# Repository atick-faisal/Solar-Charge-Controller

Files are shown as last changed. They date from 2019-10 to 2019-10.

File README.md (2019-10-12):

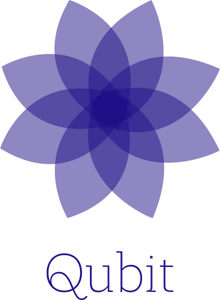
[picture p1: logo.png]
# `Solar-Charge-Controller` 
  

<p align="center">
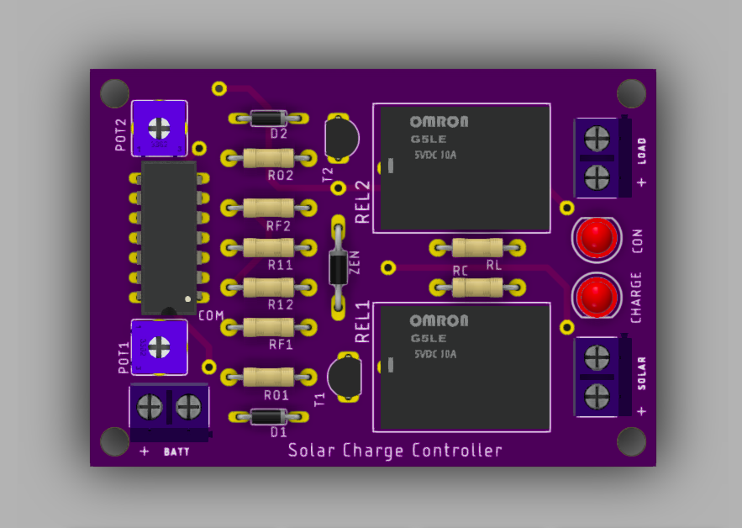
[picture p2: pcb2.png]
  
</p>
<p align="center">
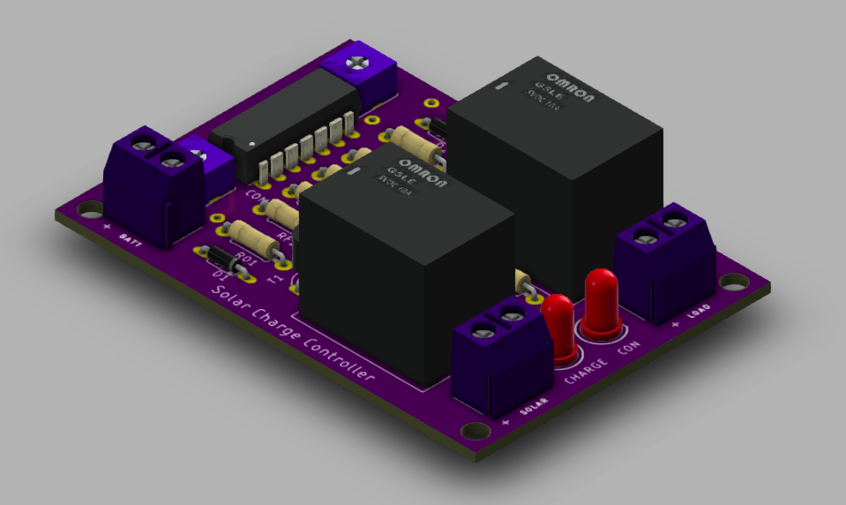
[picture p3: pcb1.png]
  
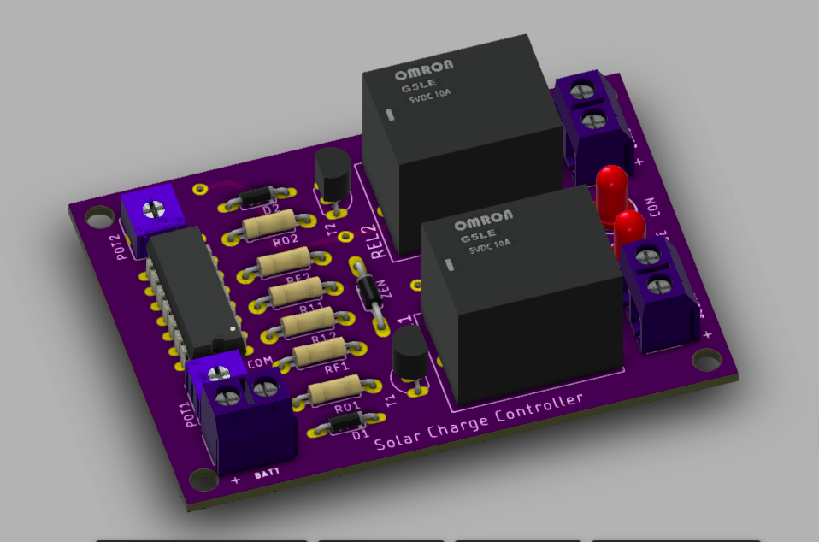
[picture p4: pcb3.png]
  
</p>

## Specifications

 ##### Battery Voltage : 12V
 ##### VR = 14.4V, ARV = 13.0V
 ##### LVD = 10.8V, LRV = 12.5V

## Schematic
<p align="center">
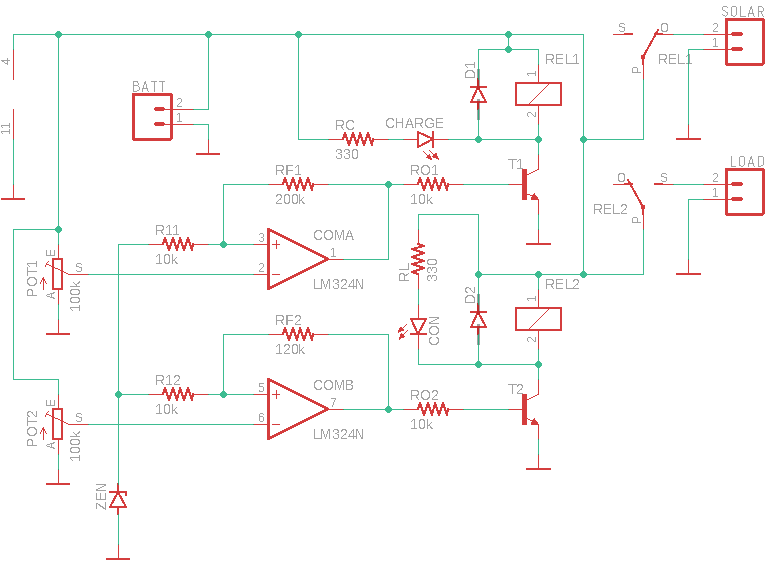
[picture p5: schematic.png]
  
</p>

## Tuning the Circuit
<p align="center">
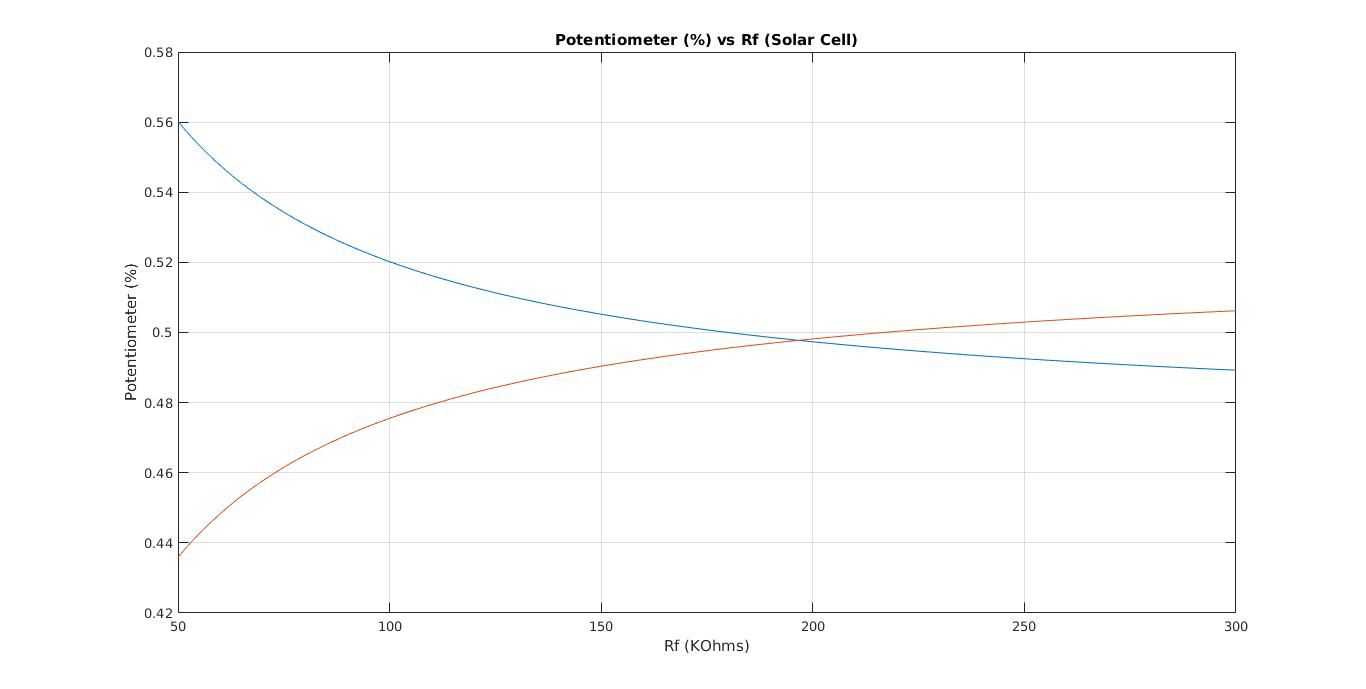
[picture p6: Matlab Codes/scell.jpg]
  
  <br>
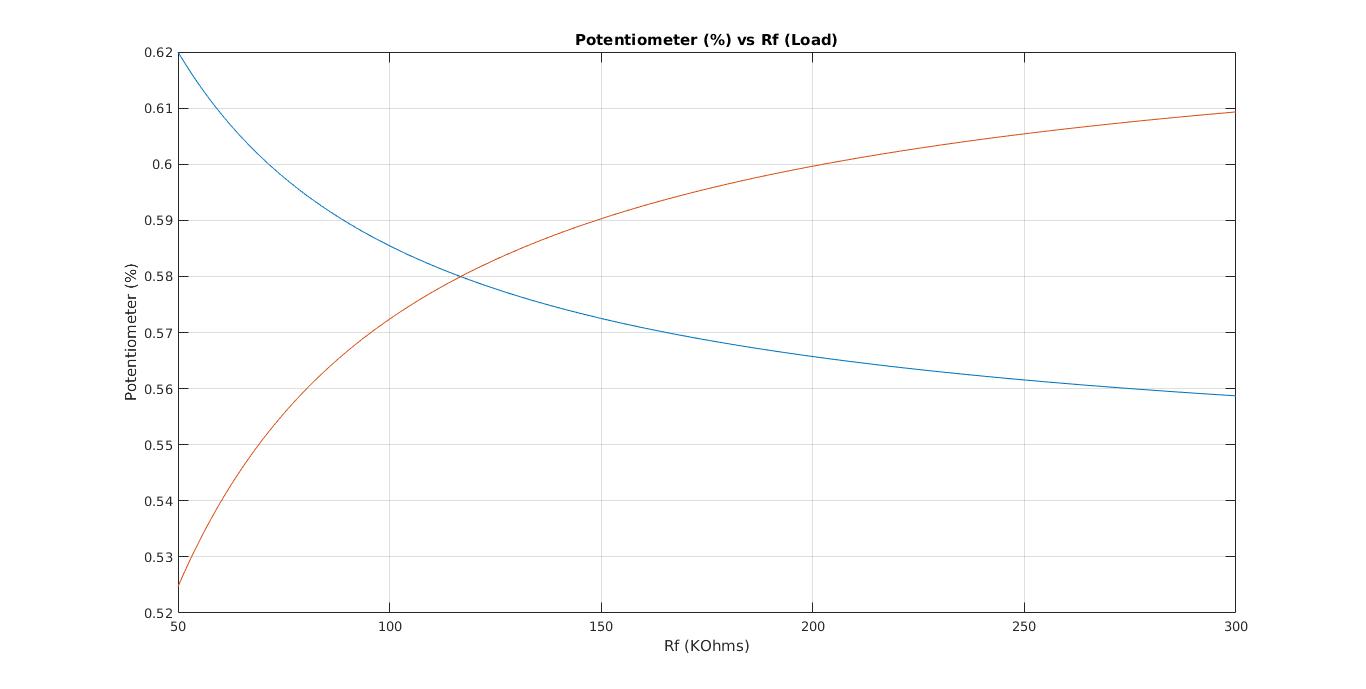
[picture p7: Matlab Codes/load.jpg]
  
</p>

## Simulation Result
<p align="center">
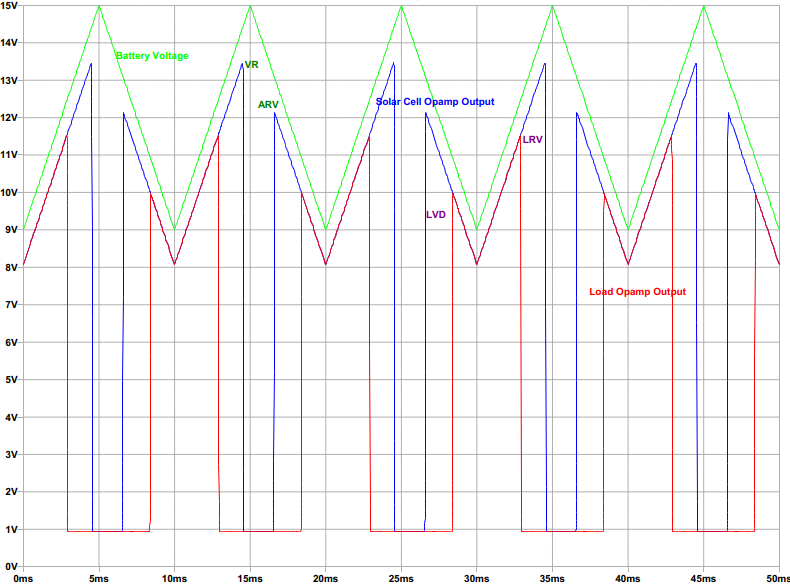
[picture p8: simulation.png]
  
</p>

## License


This work is licensed under `Apache License 2.0`

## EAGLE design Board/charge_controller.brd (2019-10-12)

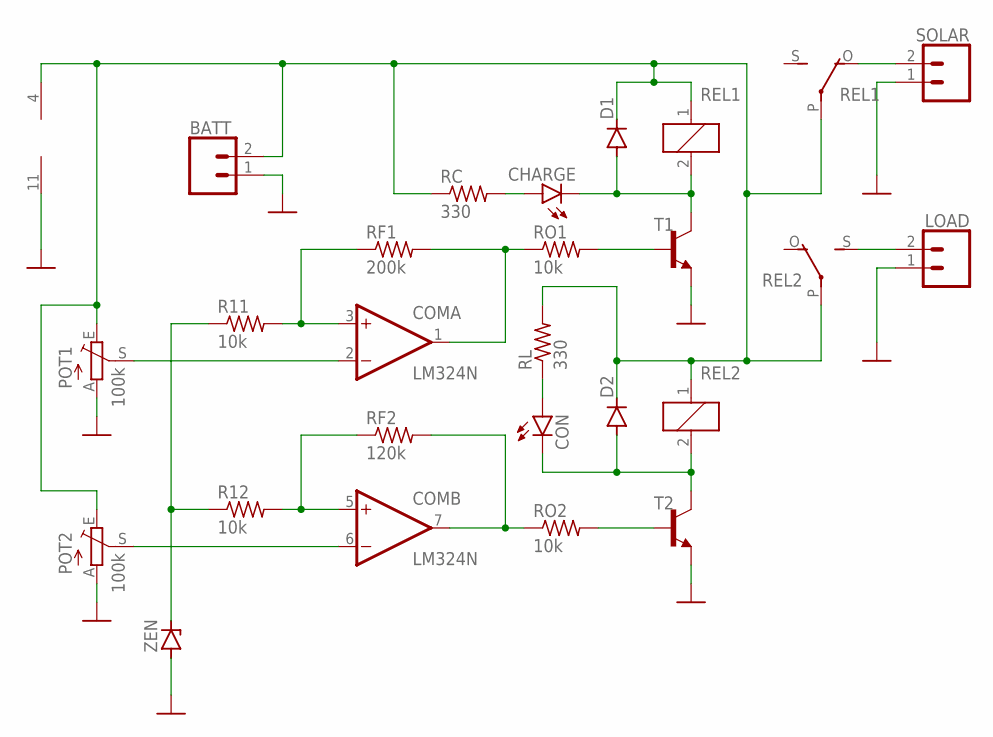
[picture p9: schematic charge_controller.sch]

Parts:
BATT: CONN_02PTH4; 1X02_XTRA_BIG
CHARGE: LED5MM
COM: LM324N; DIL14
CON: LED5MM
D1, D2: 1N4148DO35-7; DO35-7
LOAD: CONN_02PTH4; 1X02_XTRA_BIG
POT1, POT2: 100k; CT6
R11, R12: 10k; 0207/10
RC: 330; 0207/10
REL1, REL2: G5L; G5LE
RF1: 200k; 0207/10
RF2: 120k; 0207/10
RL: 330; 0207/10
RO1, RO2: 10k; 0207/10
SOLAR: CONN_02PTH4; 1X02_XTRA_BIG
T1, T2: MPS2222A-NPN-TO92-CBE; TO92-CBE
ZEN: BZD23; SOD81

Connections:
GND: BATT.1, COM.11 (V-), LOAD.1, POT1.A, POT2.A, SOLAR.1, T1.E, T2.E, ZEN.A
unnamed: COM.3 (+IN), R11.2, RF1.1
unnamed: COM.5 (+IN), R12.2, RF2.1
unnamed: COM.2 (-IN), POT1.S
unnamed: COM.6 (-IN), POT2.S
unnamed: R11.1, R12.1, ZEN.C
unnamed: COM.7 (OUT), RF2.2, RO2.1
unnamed: COM.1 (OUT), RF1.2, RO1.1
unnamed: RO1.2, T1.B
unnamed: RO2.2, T2.B
unnamed: CON.K (C), D2.A, REL2.2, T2.C
unnamed: REL1.O, SOLAR.2
unnamed: CHARGE.K (C), D1.A, REL1.2, T1.C
unnamed: LOAD.2, REL2.S
unnamed: BATT.2, COM.4 (V+), D1.C, D2.C, POT1.E, POT2.E, RC.1, REL1.1, REL1.P, REL2.1, REL2.P, RL.2
unnamed: CHARGE.A, RC.2
unnamed: CON.A, RL.1

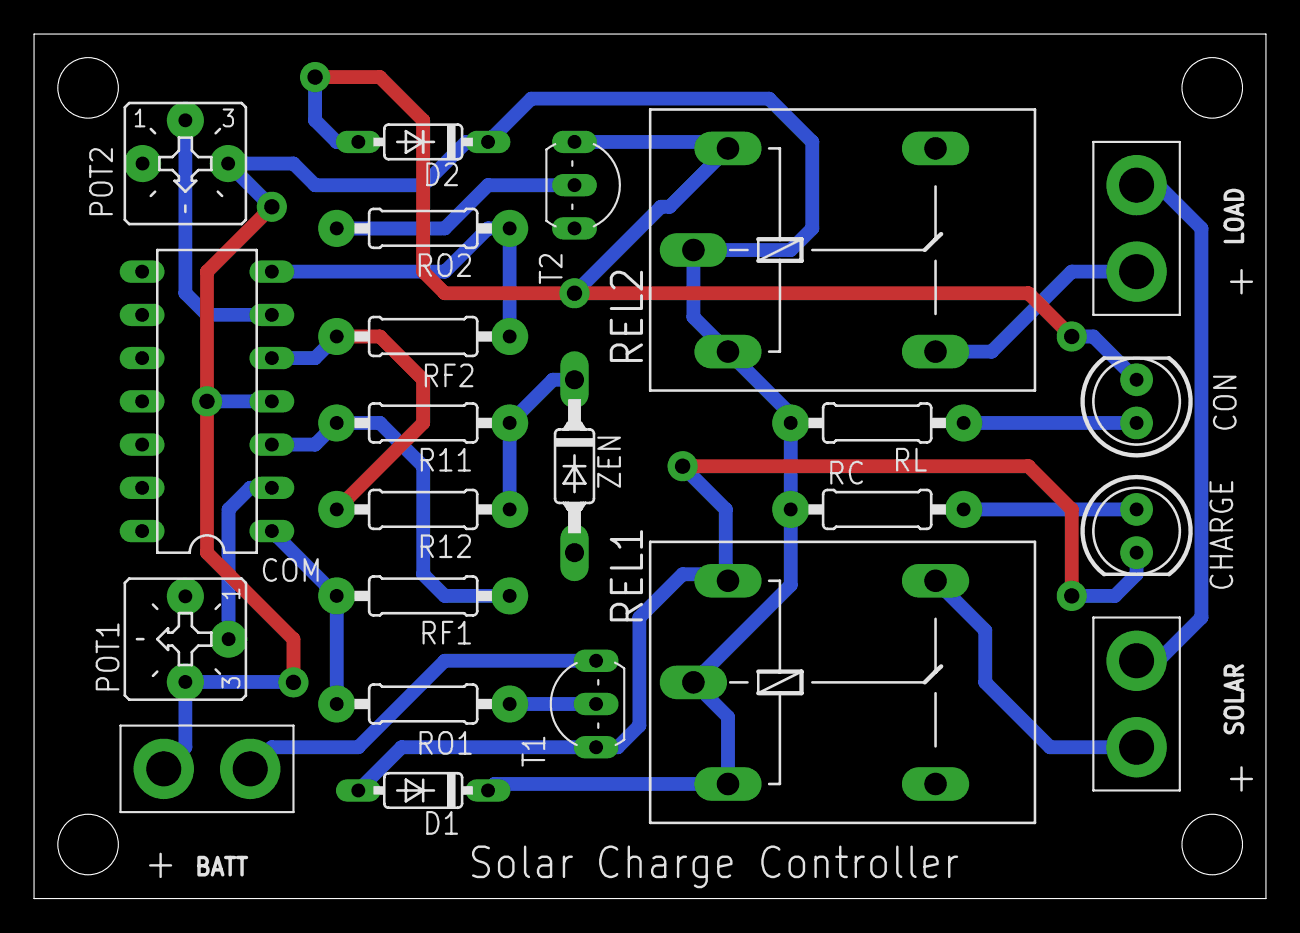
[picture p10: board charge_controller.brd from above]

Board: 2 copper layers, 72.4 x 50.8 mm, 23 parts (0 on the bottom side), 17 nets.

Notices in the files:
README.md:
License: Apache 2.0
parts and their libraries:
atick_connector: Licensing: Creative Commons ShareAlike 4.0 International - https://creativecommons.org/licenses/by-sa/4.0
